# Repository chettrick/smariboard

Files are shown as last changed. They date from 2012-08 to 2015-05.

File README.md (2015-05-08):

# smariboard
z80 single board computer for assembly language exploration

minna_schematic_v0 4-1
minna_schematic_v0 4-2

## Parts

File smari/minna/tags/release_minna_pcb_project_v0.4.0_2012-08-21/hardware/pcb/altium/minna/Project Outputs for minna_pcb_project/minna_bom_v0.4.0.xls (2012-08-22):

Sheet: Manufacturing
 | Bill of Materials - Manufacturing |  |  |  | smari minna
 | Project: | smari minna |  |  | Populate All The Resistors
 | Author: | Chris Hettrick
 | Revision: | v0.4
 | Report Date: | 2012-08-21 | 20:20:12
 | Print Date: | 2012-08-21 | 20:20:54
# | Description | Designator | Quantity | Load | Mfgr | MfgrPN | Package | Polarized | Notes
1 | CAP .10UF 16V CERAMIC X7R 0603 | C1, C2, C3, C4, C5, C6, C7, C8, C9, C10, C11, C17 | 12 | yes | Kemet | C0603C104K4RACTU | 0603 | no
2 | CAP 1.0UF 16V CERAMIC X7R 0805 | C12, C13, C18, C20 | 4 | yes | Kemet | C0805C105K4RACTU | 0805 | no
3 | CAP CER 10000PF 50V 10% X7R 0603 | C14 | 1 | yes | Kemet | C0603C103K5RACTU | 0603 | no
4 | CAP CER 47PF 50V 5% NP0 0603 | C15, C16 | 2 | yes | Kemet | C0603C470J5GACTU | 0603 | no
5 | CAPACITOR TANT 10UF 10V 10% SMD | C19 | 1 | yes | Kemet | T491A106K010AT | 1206 | yes
6 | LED SUPER RED CLEAR 0603 SMD | D1, D2, D3 | 3 | yes | Lite-On | LTST-C190KRKT | 0603 | yes
7 | DISPLAY 0.3" 627NM SGL RED SMD | DS1, DS2, DS3, DS4, DS5, DS6 | 6 | yes | Kingbright Corp | ACSC03-41EWA-F01 | SMD-10 | yes
8 | CONN RECEPT MINI USB2.0 5POS | J1 | 1 | yes | Hirose | UX60-MB-5ST | USB Mini B 5 Pin Receptacle | yes
9 | FERRITE CHIP POWER 600 OHM SMD | L1 | 1 | yes | Laird | MI0805K601R-10 | 0805 | no
10 | RES 47.0K OHM 1/10W 1% 0603 SMD | R1, R3, R9 | 3 | yes | Panasonic | ERJ-3EKF4702V | 0603 | no
11 | RES 10.0K OHM 1/10W 1% 0603 SMD | R2, R4, R5, R6, R7, R10, R19, R20, R21, R22, R23, R24, R25, R26 | 14 | yes | Panasonic | ERJ-3EKF1002V | 0603 | no
12 | RES 1.00M OHM 1/10W 1% 0603 SMD | R8 | 1 | yes | Panasonic | ERJ-3EKF1004V | 0603 | no
13 | RES 680 OHM 1/10W 1% 0603 SMD | R11, R12, R13, R14, R15, R16, R17, R18, R36, R37 | 10 | yes | Panasonic | ERJ-3EKF6800V | 0603 | no
14 | RES 18.0K OHM 1/10W 1% 0603 SMD | R27, R28, R29 | 3 | yes | Panasonic | ERJ-3EKF1802V | 0603 | no
15 | RES 1.00K OHM 1/10W 1% 0603 SMD | R30, R31 | 2 | yes | Panasonic | ERJ-3EKF1001V | 0603 | no
16 | RES 27.0 OHM 1/10W 1% 0603 SMD | R32, R34 | 2 | yes | Panasonic | ERJ-3EKF27R0V | 0603 | no
17 | RES 160 OHM 1/10W 1% 0603 SMD | R33, R35 | 2 | yes | Panasonic | ERJ-3EKF1600V | 0603 | no
18 | SWITCH TACT 6MM 160GF H=4.3MM | SW0, SW1, SW2, SW3, SW6, SW7, SW8, SW9, SW12, SW13, SW14, SW15, SW16, SW17, SW18, SW19, SW20, SW21, SW22, SW23, SW24, SW25, SW26, SW27, SW28, SW29, SW30, SW31, SW32, SW33, SW34, SW35, SW40, SW41, SW42, SW43 | 36 | yes | C&K Components | PTS645SM43SMTR LFS | SMD-6x6 | yes
19 | IC Z80 CPU CMOS 10MHZ 44LQFP | U1 | 1 | yes | Zilog | Z84C0010AEG | LQFP-44 | yes | CPU Z80 8 BIT 10MHZ
20 | IC FLASH MPF 1MBIT 70NS 32TSOP | U2 | 1 | yes | SST | SST39SF010A-70-4C-WHE | TSOP-32 | yes | FLASH 0000H-7FFFH
21 | IC SRAM 256KBIT 45NS 28TSOP | U3 | 1 | yes | ISSI | IS62C256AL-45TLI | TSOP-28 | yes | RAM 8000H-FFFFH
22 | IC COUNTER DECADE 4BIT 14SOIC | U4 | 1 | yes | Texas Instruments | SN74LS90DG4 | SOIC-14 | yes
23 | IC HEX SCHMITT-TRIG INV 14-TSSOP | U5, U9 | 2 | yes | Texas Instruments | SN74HC14PWR | TSSOP-14 | yes
24 | IC DUAL F-F W/CLR/PRESET 14TSSOP | U6 | 1 | yes | Texas Instruments | SN74HC74PWR | TSSOP-14 | yes
25 | IC MUX/DECODER SNGL 1OF2 SOT23-6 | U7 | 1 | yes | Texas Instruments | SN74LVC1G19DBVR | TSSOP-6 | yes | ADDRESS DECODER
26 | IC BUFF/DVR TRI-ST 8BIT 20TSSOP | U8 | 1 | yes | Texas Instruments | SN74HC541PWR | TSSOP-20 | yes
27 | IC I/O EXPANDER 24B 44MQFP | U10 | 1 | yes | Intersil | CQ82C55AZ | MQFP-44 | yes | IO PORT EXPANDER 00H-03H
28 | IC DUAL 4-IN NOR GATE 14TSSOP | U11 | 1 | yes | Texas Instruments | CD74HC4002PWR | TSSOP-14 | yes
29 | IC USB FS I2C SSOP-16 | U12 | 1 | yes | FTDI | FT201XS-R | SSOP-16 | yes | USB TO I2C INTERFACE
30 | RESONATOR CER 3.58MHZ W/CAP SMD | X1 | 1 | yes | Abracon | AWSCR-3.58MGD-T | SMD-7.4x3.4 | no
31 | CONN CARD EDGE 40PIN GOLD | J2 | 1 | DNP | CW Industries | CWR-170-40-0000 |  | yes | Z80 CARD EDGE CONNECTION
32 | RES 0.0 OHM 1/10W 0603 SMD | R38 | 1 | DNP | Panasonic | ERJ-3GEY0R00V | 0603 | no | jumper
Notes

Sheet: Purchasing
 | Bill of Materials - Purchasing |  |  |  | smari minna
 | Project: | smari minna |  |  | Populate All The Resistors
 | Author: | Chris Hettrick
 | Revision: | v0.4
 | Report Date: | 2012-08-21 | 20:20:12
 | Print Date: | 2012-08-21 | 20:20:54
# | Description | Designator | Quantity | Load | Mfgr | MfgrPN | Package | Dist | DistPN
1 | CAP .10UF 16V CERAMIC X7R 0603 | C1, C2, C3, C4, C5, C6, C7, C8, C9, C10, C11, C17 | 12 | yes | Kemet | C0603C104K4RACTU | 0603 | Digikey | 399-1096-1-ND
2 | CAP 1.0UF 16V CERAMIC X7R 0805 | C12, C13, C18, C20 | 4 | yes | Kemet | C0805C105K4RACTU | 0805 | Digikey | 399-1284-1-ND
3 | CAP CER 10000PF 50V 10% X7R 0603 | C14 | 1 | yes | Kemet | C0603C103K5RACTU | 0603 | Digikey | 399-1091-1-ND
4 | CAP CER 47PF 50V 5% NP0 0603 | C15, C16 | 2 | yes | Kemet | C0603C470J5GACTU | 0603 | Digikey | 399-1056-1-ND
5 | CAPACITOR TANT 10UF 10V 10% SMD | C19 | 1 | yes | Kemet | T491A106K010AT | 1206 | Digikey | 399-3684-1-ND
6 | LED SUPER RED CLEAR 0603 SMD | D1, D2, D3 | 3 | yes | Lite-On | LTST-C190KRKT | 0603 | Digikey | 160-1436-2-ND
7 | DISPLAY 0.3" 627NM SGL RED SMD | DS1, DS2, DS3, DS4, DS5, DS6 | 6 | yes | Kingbright Corp | ACSC03-41EWA-F01 | SMD-10 | Digikey | 754-1037-1-ND
8 | CONN RECEPT MINI USB2.0 5POS | J1 | 1 | yes | Hirose | UX60-MB-5ST | USB Mini B 5 Pin Receptacle | Digikey | H2959CT-ND
9 | FERRITE CHIP POWER 600 OHM SMD | L1 | 1 | yes | Laird | MI0805K601R-10 | 0805 | Digikey | 240-2390-1-ND
10 | RES 47.0K OHM 1/10W 1% 0603 SMD | R1, R3, R9 | 3 | yes | Panasonic | ERJ-3EKF4702V | 0603 | Digikey | P47.0KHCT-ND
11 | RES 10.0K OHM 1/10W 1% 0603 SMD | R2, R4, R5, R6, R7, R10, R19, R20, R21, R22, R23, R24, R25, R26 | 14 | yes | Panasonic | ERJ-3EKF1002V | 0603 | Digikey | P10.0KHCT-ND
12 | RES 1.00M OHM 1/10W 1% 0603 SMD | R8 | 1 | yes | Panasonic | ERJ-3EKF1004V | 0603 | Digikey | P1.00MHCT-ND
13 | RES 680 OHM 1/10W 1% 0603 SMD | R11, R12, R13, R14, R15, R16, R17, R18, R36, R37 | 10 | yes | Panasonic | ERJ-3EKF6800V | 0603 | Digikey | P680HCT-ND
14 | RES 18.0K OHM 1/10W 1% 0603 SMD | R27, R28, R29 | 3 | yes | Panasonic | ERJ-3EKF1802V | 0603 | Digikey | P18.0KHCT-ND
15 | RES 1.00K OHM 1/10W 1% 0603 SMD | R30, R31 | 2 | yes | Panasonic | ERJ-3EKF1001V | 0603 | Digikey | P1.00KHCT-ND
16 | RES 27.0 OHM 1/10W 1% 0603 SMD | R32, R34 | 2 | yes | Panasonic | ERJ-3EKF27R0V | 0603 | Digikey | P27.0HCT-ND
17 | RES 160 OHM 1/10W 1% 0603 SMD | R33, R35 | 2 | yes | Panasonic | ERJ-3EKF1600V | 0603 | Digikey | P160HCT-ND
18 | SWITCH TACT 6MM 160GF H=4.3MM | SW0, SW1, SW2, SW3, SW6, SW7, SW8, SW9, SW12, SW13, SW14, SW15, SW16, SW17, SW18, SW19, SW20, SW21, SW22, SW23, SW24, SW25, SW26, SW27, SW28, SW29, SW30, SW31, SW32, SW33, SW34, SW35, SW40, SW41, SW42, SW43 | 36 | yes | C&K Components | PTS645SM43SMTR LFS | SMD-6x6 | Digikey | CKN9112CT-ND
19 | IC Z80 CPU CMOS 10MHZ 44LQFP | U1 | 1 | yes | Zilog | Z84C0010AEG | LQFP-44 | Digikey | 269-4574-ND
20 | IC FLASH MPF 1MBIT 70NS 32TSOP | U2 | 1 | yes | SST | SST39SF010A-70-4C-WHE | TSOP-32 | Digikey | SST39SF010A-70-4C-WHE-ND
21 | IC SRAM 256KBIT 45NS 28TSOP | U3 | 1 | yes | ISSI | IS62C256AL-45TLI | TSOP-28 | Digikey | 706-1109-ND
22 | IC COUNTER DECADE 4BIT 14SOIC | U4 | 1 | yes | Texas Instruments | SN74LS90DG4 | SOIC-14 | Digikey | 296-3746-5-ND
23 | IC HEX SCHMITT-TRIG INV 14-TSSOP | U5, U9 | 2 | yes | Texas Instruments | SN74HC14PWR | TSSOP-14 | Digikey | 296-8234-1-ND
24 | IC DUAL F-F W/CLR/PRESET 14TSSOP | U6 | 1 | yes | Texas Instruments | SN74HC74PWR | TSSOP-14 | Digikey | 296-8372-1-ND
25 | IC MUX/DECODER SNGL 1OF2 SOT23-6 | U7 | 1 | yes | Texas Instruments | SN74LVC1G19DBVR | TSSOP-6 | Digikey | 296-16982-1-ND
26 | IC BUFF/DVR TRI-ST 8BIT 20TSSOP | U8 | 1 | yes | Texas Instruments | SN74HC541PWR | TSSOP-20 | Digikey | 296-8335-1-ND
27 | IC I/O EXPANDER 24B 44MQFP | U10 | 1 | yes | Intersil | CQ82C55AZ | MQFP-44 | Digikey | CQ82C55AZ-ND
28 | IC DUAL 4-IN NOR GATE 14TSSOP | U11 | 1 | yes | Texas Instruments | CD74HC4002PWR | TSSOP-14 | Digikey | 296-31585-1-ND
29 | IC USB FS I2C SSOP-16 | U12 | 1 | yes | FTDI | FT201XS-R | SSOP-16 | Digikey | 768-1136-1-ND
30 | RESONATOR CER 3.58MHZ W/CAP SMD | X1 | 1 | yes | Abracon | AWSCR-3.58MGD-T | SMD-7.4x3.4 | Digikey | 535-9365-1-ND
31 | CONN CARD EDGE 40PIN GOLD | J2 | 1 | DNP | CW Industries | CWR-170-40-0000 |  | Digikey | CCE40G-ND
32 | RES 0.0 OHM 1/10W 0603 SMD | R38 | 1 | DNP | Panasonic | ERJ-3GEY0R00V | 0603 | Digikey | P0.0GCT-ND
Notes

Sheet: Revision History
Revision History
Revision | Description | Author | Date

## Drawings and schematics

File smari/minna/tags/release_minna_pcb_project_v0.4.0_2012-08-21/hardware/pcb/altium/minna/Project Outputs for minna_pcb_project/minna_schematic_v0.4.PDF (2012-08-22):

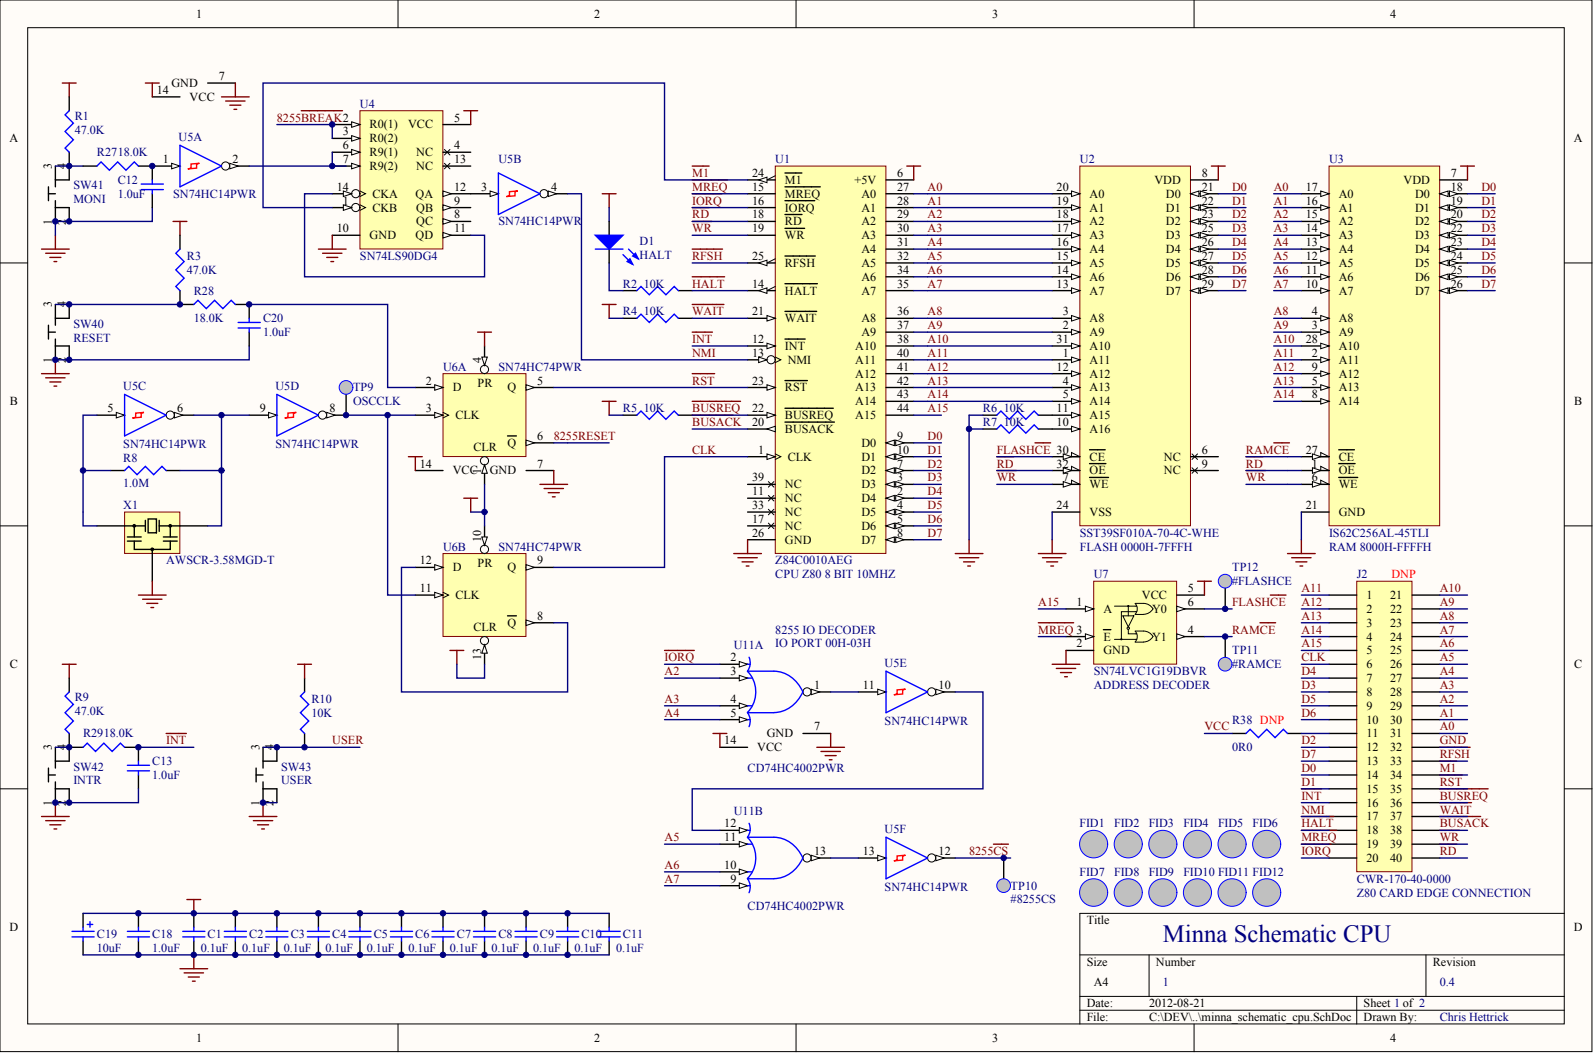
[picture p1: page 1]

OSCCLK | | BUSACK 8255RESET | BUSACK 20 | A14 | A14 5

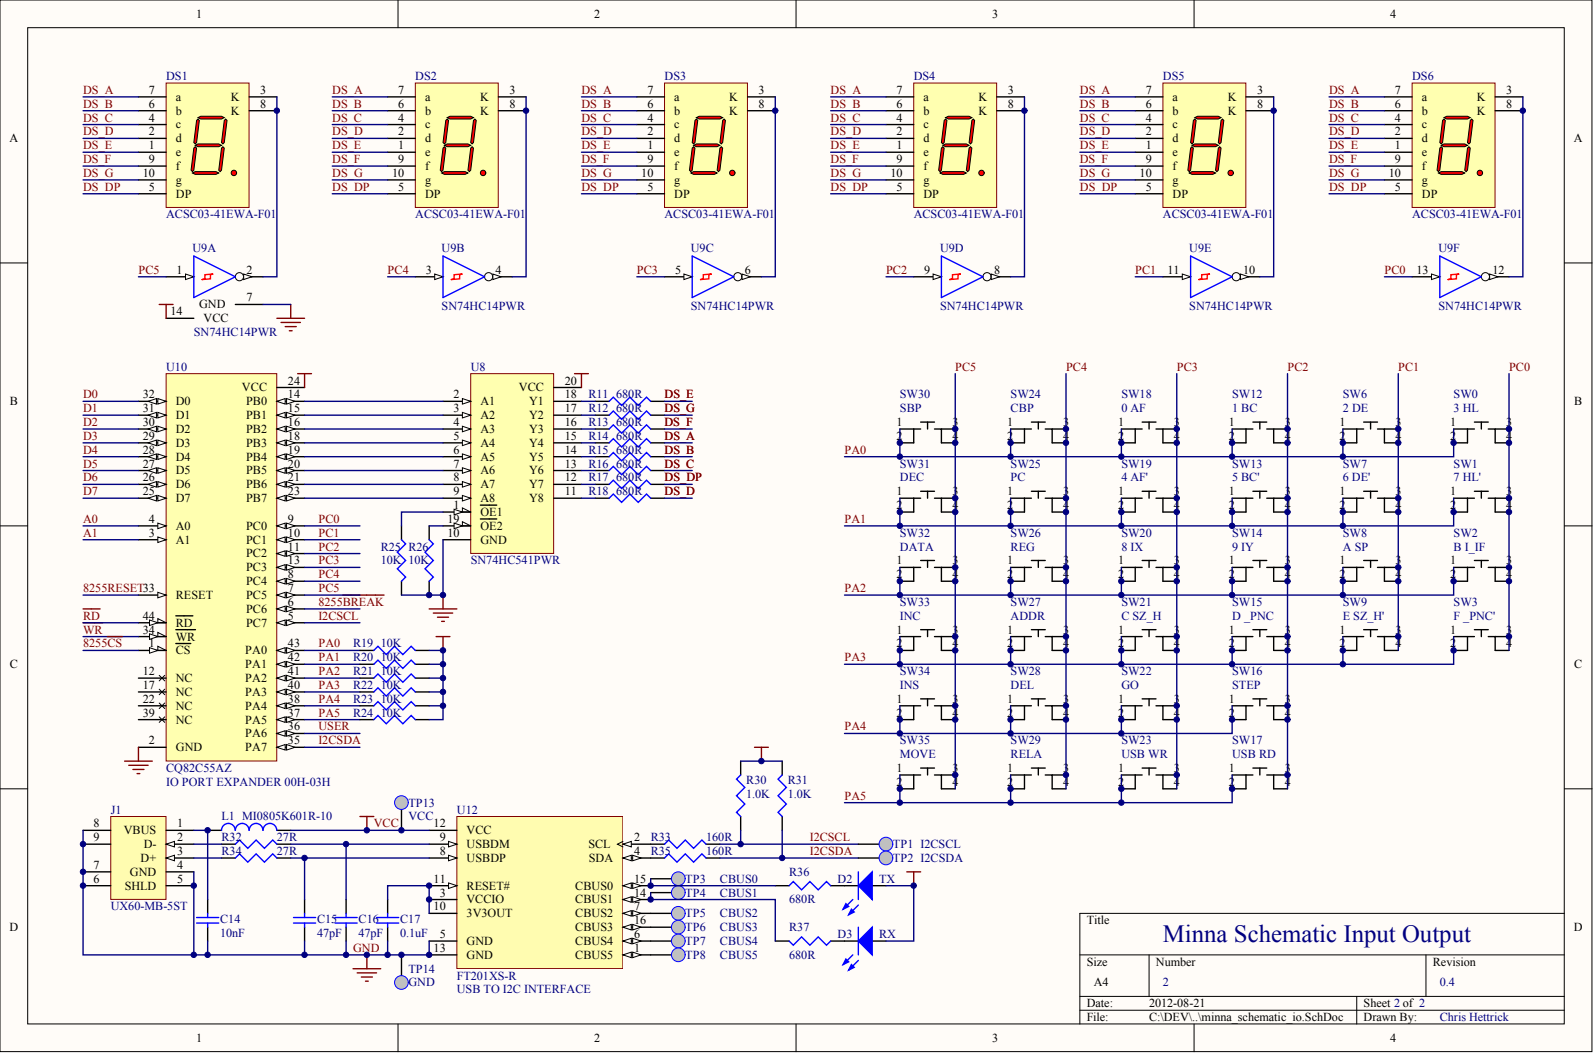
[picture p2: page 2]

SW26 REG | SW20 8 IX | SW14 9 IY | SW8 A SP

Minna Schematic Input Output

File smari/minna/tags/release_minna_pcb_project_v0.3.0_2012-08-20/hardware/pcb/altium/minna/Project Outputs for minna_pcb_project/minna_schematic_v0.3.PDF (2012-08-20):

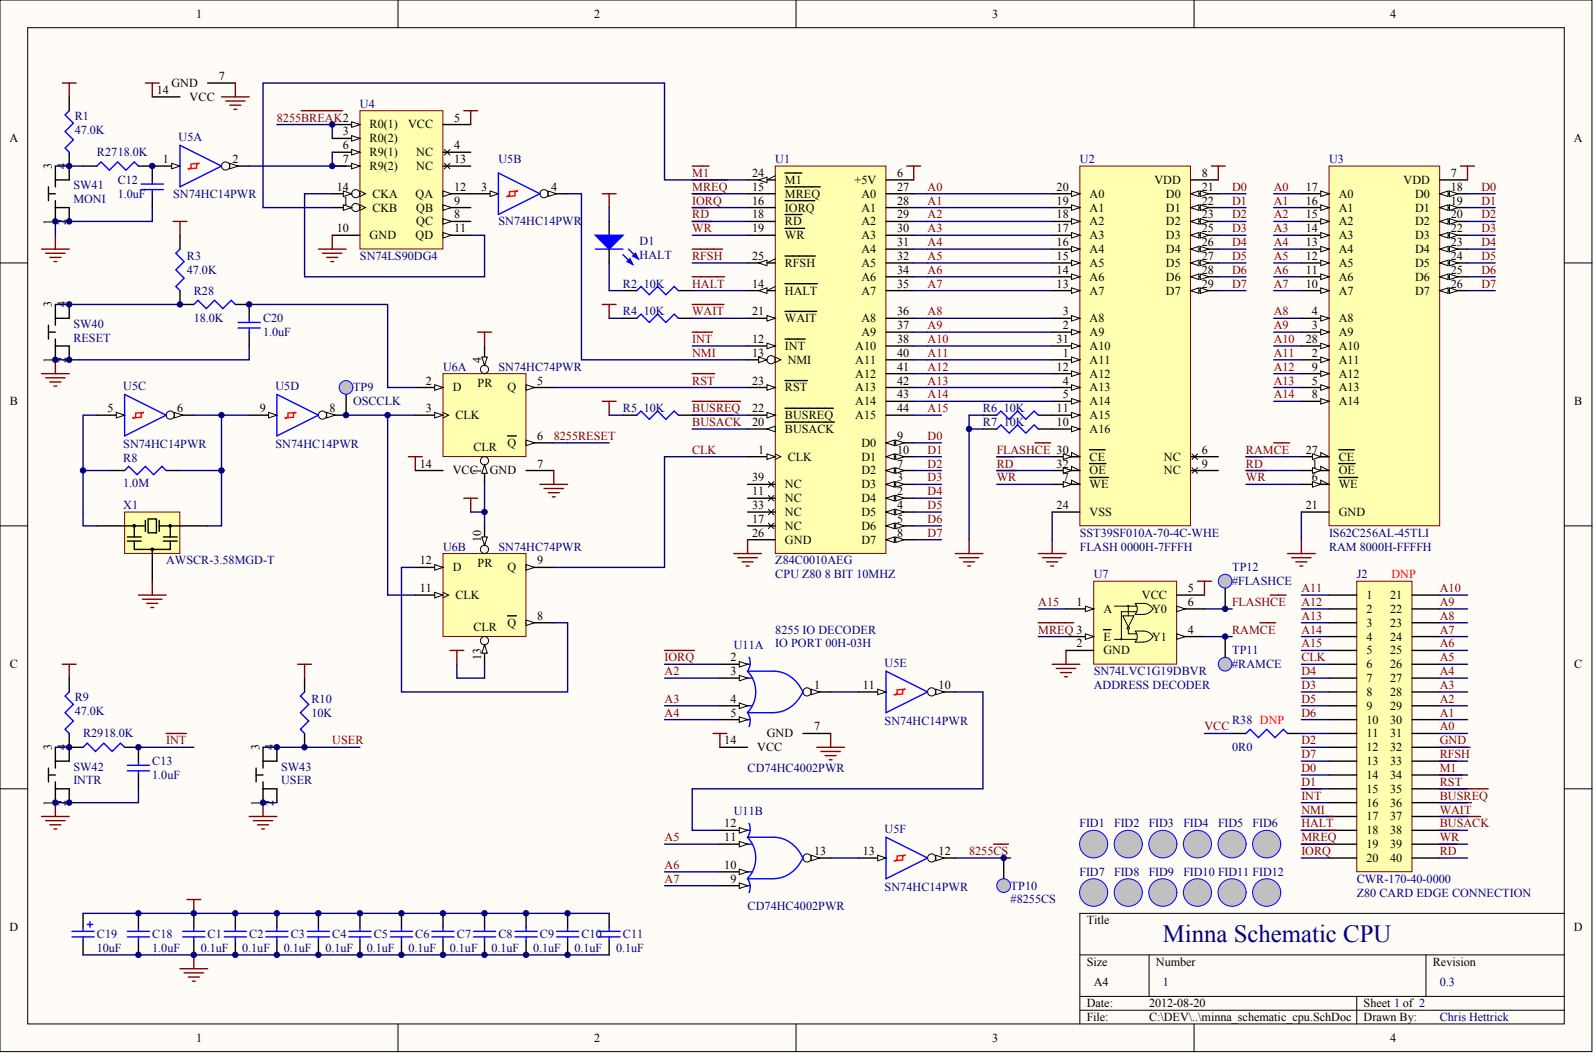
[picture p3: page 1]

OSCCLK | | BUSACK 8255RESET | BUSACK 20 | A14 | A14 5

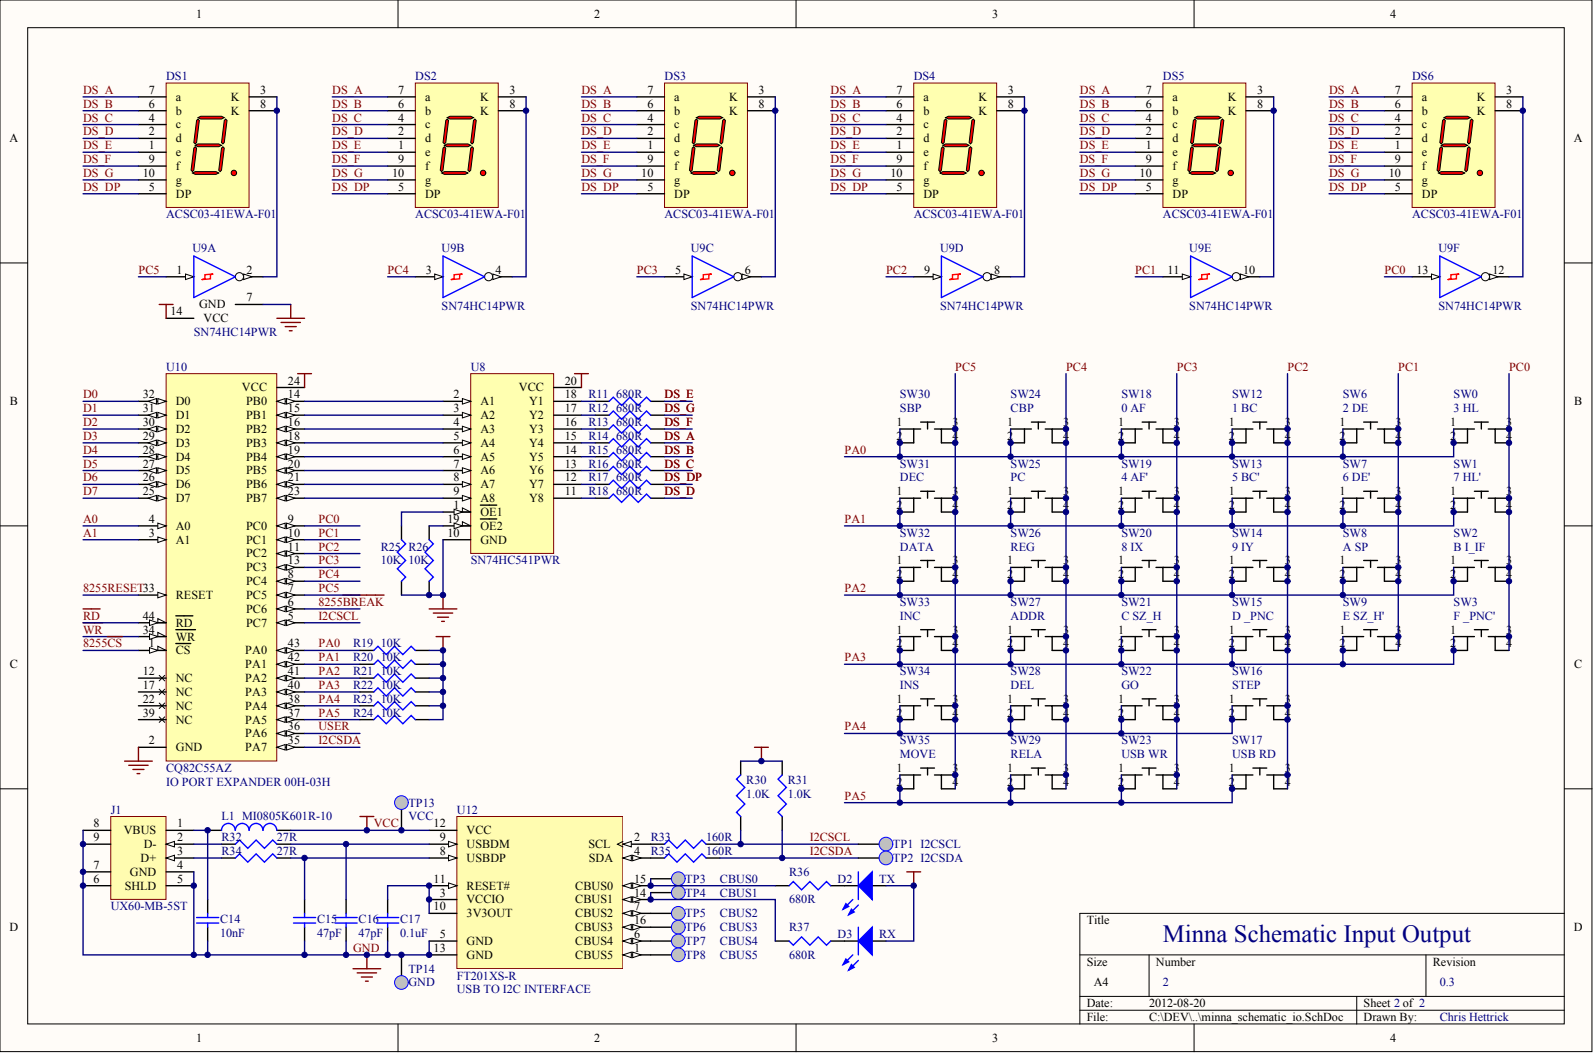
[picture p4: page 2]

SW26 REG | SW20 8 IX | SW14 9 IY | SW8 A SP

Minna Schematic Input Output

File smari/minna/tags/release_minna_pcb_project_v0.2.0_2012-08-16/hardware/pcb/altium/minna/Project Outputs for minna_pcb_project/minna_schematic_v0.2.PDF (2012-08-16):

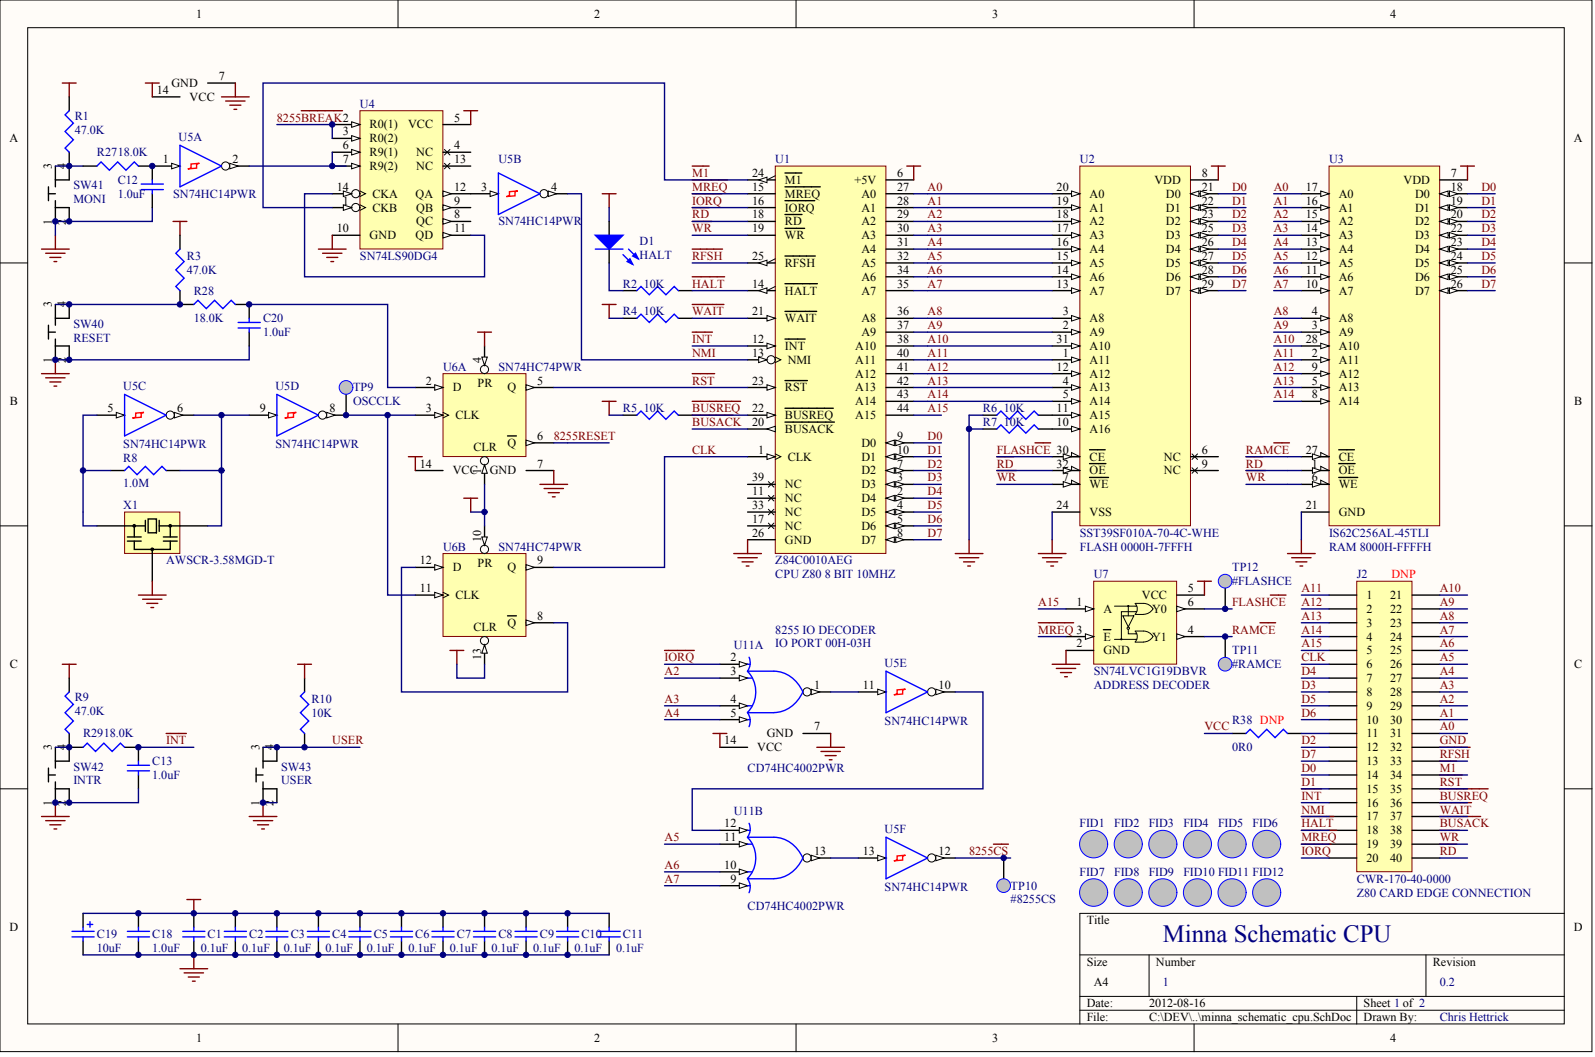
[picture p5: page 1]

OSCCLK | | BUSACK 8255RESET | BUSACK 20 | A14 | A14 5

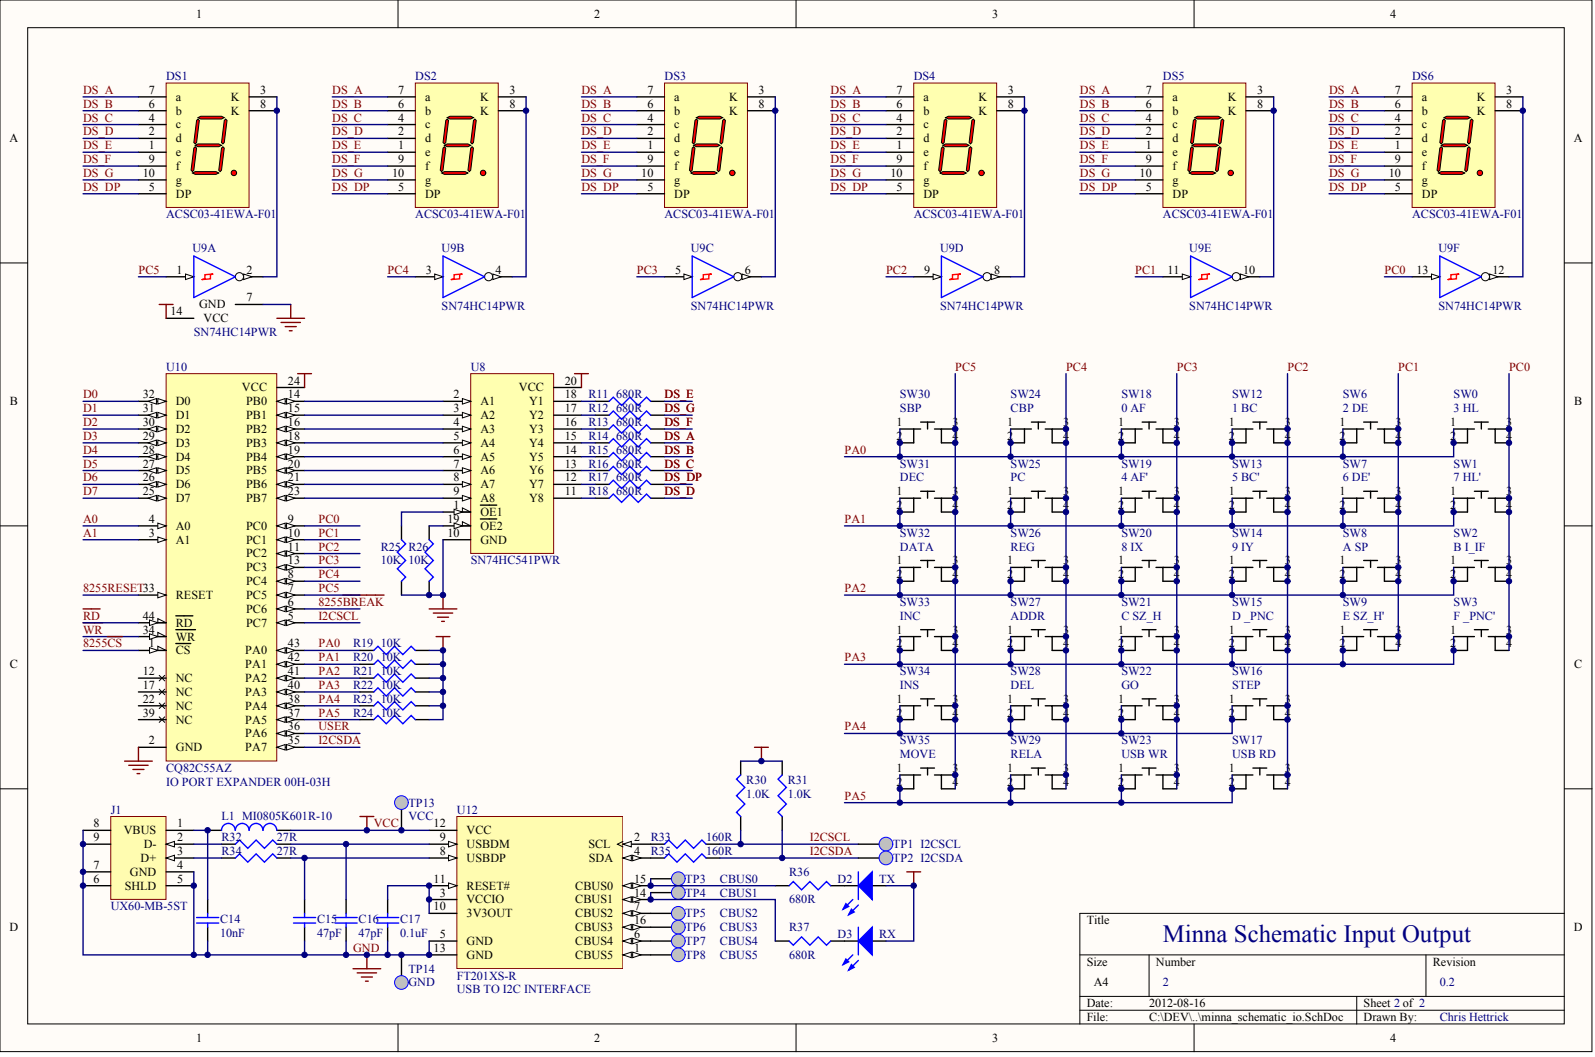
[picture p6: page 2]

SW26 REG | SW20 8 IX | SW14 9 IY | SW8 A SP

Minna Schematic Input Output

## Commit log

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2011-12-26 Import of minna v0.1 schematic and PCB design files. The design has almost achieved output status at this point, before version control.
    [Minna Project.PcbLib, Minna Project.PrjPCB, Minna Project.SchLib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]
2011-12-26 Added files under 'smari' folder, where it should be. That lets it be easier to find different projects in the future.
    [Minna Project.PcbLib, Minna Project.PrjPCB, Minna Project.SchLib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]
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2011-12-28 Fixed up the look of minna_v01/Minna_V01.PcbDoc by adding a sheet, dimensions and layer stackup.
    [Minna Project.PrjPCB, Minna_IO.SchDoc, Minna_V01.PcbDoc]
2011-12-28 Updated the bill of materials spreadsheet template to have an accurate BOM for purchasing and assembly.
    [Minna Project.PrjPCB, Minna_CPU.SchDoc, Minna_IO.SchDoc]
2011-12-28 Fixed power and ground planes. PCB is now a four layer board instead of a 2 layer board. The reason is that I didn't route power and ground before the signal wires (I didn't know if it would all fit 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
    Routed a lot of the power and ground wires. They are all that are left for the electrical connections. The rest is just cosmetic (fiducials, etc).
    [Minna Project.PrjPCB, Minna_V01.PcbDoc]
2011-12-29 A whole bunch of work was done on the PCB tonight. I added the bridge rectifier so that any polarity of barrel jack used for power will work with the PCB and wont kill it. Also, cleaned up some of th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
    TODO:
    Check that all .Designators are in right orientation.
    Finish wiring up VCC and GND. Find out how the best way to give the power to the planes.
    Add finishing touches like 'scope test points, etc.
    [Minna Project.PcbLib, Minna Project.PrjPCB, Minna Project.SchLib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]
2012-03-10 Worked on the power delivery a little bit. Nothing fancy
    [Minna Project.PcbLib, Minna Project.PrjPCB, Minna_V01.PcbDoc]
2012-05-07 Fixed up some stuff. I don't really remember what it was though, as the changes were weeks ago! I think I worked on the power supply a little bit.
    [Minna Project.PrjPCB, Minna Project.SchLib, Minna_CPU.SchDoc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]
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2012-07-04 Updated some library parts for consistency across all items. Did lots of work on the Console schematics. Still need to figure out the address load circuit. Added new location of schematic and pcb lib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
    [console_pcb_project.PrjPcb, console_schematic_logic.SchDoc, console_schematic_switches.SchDoc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]
2012-07-04 Finished the schematics. Added a Load circuit for the address buses. Could not minimize the inverter count from 19 to 18, so instead there will be dedicated inverter chips for each section of the cir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
    [console_pcb.PcbDoc, console_pcb_project.PrjPcb, console_schematic_logic.SchDoc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]
2012-07-04 Schematic library updates and fixes where the old library name was referenced. Also, one item had two footprints, one which was non-existent.
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2012-07-08 Lots of work done: Missed some power ports on schematic symbols that didn't show them, so they were added. Renamed a couple parts so it would be easier to troubleshoot the PCB. Rough mock-up of compo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
    [console_pcb.PcbDoc, console_pcb_project.PrjPcb, console_schematic_logic.SchDoc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]
2012-07-08 Just some small footprint error in the component outline fixed. I should go over all the schematics so that they reference the updated name of the component libraries.
    [minna_pcb.PcbDoc, minna_schematic_cpu.SchDoc]
2012-07-12 Solidified the placement of all components, except the card edge connector. I think it should be on the right side of the PCB, same as the minna. Placement of all parts is in alignment with each othe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
    [console_pcb.PcbDoc, console_pcb_project.PrjPcb, console_schematic_logic.SchDoc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]
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2012-07-30 Did lots of work on the pcb: Finished the power grid. Started on all the signal connections.
    [console_pcb.PcbDoc, console_pcb_project.PrjPcb, console_schematic_logic.SchDoc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]
2012-07-30 Moved the pcb out from 3600 mils to 3700 mils to be even on both sides of the buttons.
    [minna_pcb.PcbDoc, minna_pcb_project.PrjPCB]
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2012-08-01 Changed all the non-software debounced switches to have a hardware debounce circuit. Still need to route the rest of the new parts.
    [minna_pcb.PcbDoc, minna_pcb_project.PrjPCB, minna_schematic_cpu.SchDoc]
2012-08-03 Added debouncing circuit to interrupt and monitor switches. The RC debounce circuit came from Jack Ganssle's article on the same. There is an RC circuit on both charging and discharging, instead of t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
    [minna_schematic_cpu.SchDoc]
2012-08-03 Arranged the new caps and resistors for the interrupt and monitor switch circuits.
    [minna_pcb.PcbDoc]
2012-08-03 Removed the barrel jack power supply and all associated parts (like bridge rectifier) and replaced it with USB parts. The USB to I2C driver is the FT201XS-R. This will give I2C capabilities to the 82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
    [minna_pcb.PcbDoc, minna_schematic_cpu.SchDoc, minna_schematic_io.SchDoc]
2012-08-06 Finished all PCB routing. Adjusted .Designators and the silkscreen part designators. Added `Populate All the Resistors' to the bottom layer. Added `SMARI' to the bottom silkscreen layer. Cleaned up t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
    [minna_pcb.PcbDoc, minna_pcb_project.PrjPCB, minna_schematic_cpu.SchDoc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]
2012-08-07 This is the tagged v0.1 release of smari minna pcb SVN revision level 69. Lots are included in this revision. OutJobs are fixed up and are giving good project outputs. Fixed two track errors that the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
    [minna_bom_v0.1.0.xls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]
2012-08-07 Tagged release of smari minna v0.1 pcb project on August 06 2012.
    [minna_bom_v0.1.0.xls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]
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2012-08-16 Rule for soldermask expansion was not defined (was at 0 mils). Changed to 6 mils as per Advanced Circuits. Lowered track width on USB connections to 12 mils. Adjusted via placement because of insuffi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
    [minna_pcb.PcbDoc]
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2012-08-16 Added a 0 ohm jumper to the VCC pin on card edge connector. It is Do Not Populate.
    [minna_schematic_cpu.SchDoc]
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2012-08-16 Updated assembly output job file. Updated board outline, drill outline, dimensions, and text for card edge chamfers. Changed schematic and pcb sheets to v0.2. Updated silkscreen for tagged revision (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
    [minna_bom_v0.2.0.xls, minna_pcb.PcbDoc, minna_pcb_project.PrjPCB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]
2012-08-16 This is the tagged v0.2.0 release of the minna pcb project. Errors reported by Advanced Circuit's FreeDFM service are fixed. Added information for chamfering the edge connector. Added jumper to card 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
    [minna_bom_v0.1.0.xls, minna_bom_v0.2.0.xls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]
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2012-08-17 Changed drills precision from 2.5 to 2.4 as per OSH Park requirements. Stopped some automated reports from opening. Minor fixes.
2012-08-17 Changed the card edge chamfer angle from 45 degrees to 30 degrees. Drills and ODB++ format from 2.5 to 2.4 precision. Expanded the card edge solder mask from 0 mils to 6 mils around all pads.
    [minna_pcb.PcbDoc, minna_pcb_project.PrjPCB]
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2012-08-20 PCB: Z80, 7 segment, and T491A footprints updated, and all associated tracks were fixed. All text strings updated to the v0.3 r91 2012-08-20 release that is immediately after this commit. SCH: All do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
    [minna_bom_v0.2.0.xls, minna_bom_v0.3.0.xls, minna_pcb.PcbDoc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]
2012-08-20 TAG: v0.3.0 tag at v90 on August 20 2012. This is the third prototype release, but first release that will actually be fabricated (if all goes good).
    [minna_bom_v0.3.0.xls, minna_pcb.PcbDoc, minna_pcb_project.PrjPCB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]
2012-08-20 OSH Park has a stupid online file submission program and doesn't detect if this is a two or four layer PCB. Hopefully these files will help out.
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2012-08-22 PCB: Added two internal planes (as "signal" layers) for power and ground with polygon pours and connected to either VCC or GND. Moved some vias for better polygon fills. Updated parameters to v0.4. S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
    [minna_bom_v0.3.0.xls, minna_bom_v0.4.0.xls, minna_pcb.PcbDoc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]
2012-08-22 TAG AT V95: This is the v0.4.0 release of the smari minna Z80 project. Added positive internal power planes.
    [minna_bom_v0.4.0.xls, minna_pcb.PcbDoc, minna_pcb_project.PrjPCB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]
2012-08-25 SCH: Added unused parts to schematics for logic ICs. PCB: Added board outline layer and outline. Fixed card edge connector as per minna v0.4 PCB. Routed more connections. Moved some capacitors where 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
    [console_pcb.PcbDoc, console_pcb_project.PrjPcb, console_schematic_logic.SchDoc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]
2012-08-26 PCB: Did lots of routing on the lower half of the PCB. Most tracks are routed, except the card edge tracks. DESIGN: Perhaps the card edge connector should be along to top of the PCB? It might fit bet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
    [console_pcb.PcbDoc, console_pcb_project.PrjPcb]
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2012-09-25 PCB: Branched for a four layer PCB, instead of the desired two layer PCB.
    [console_pcb.PcbDoc, console_pcb_project.PrjPcb, console_schematic_logic.SchDoc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]
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
